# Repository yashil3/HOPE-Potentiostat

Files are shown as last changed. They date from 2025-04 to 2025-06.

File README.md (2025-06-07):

# Pocket Potentiostat
IEEE DeCal HOPE Final Project -- Potentiostat for applying cyclic voltammetry to electrolyte

- Blocks A, B, D, and E: uses OPA2277 high-precision operational amplifiers
- Block C: uses TL074 transimpedance amplifier
- Blocks F, G, and H: uses INA128 instrumentational amplifiers
- Block C uses a TL074 Transimpedance Amplifier (TIA). It is cost-effective, but it is not the best option (a really good one would be ~$40)
- May need to fix Rg resistor values based on how much the voltage in the electrodes varies

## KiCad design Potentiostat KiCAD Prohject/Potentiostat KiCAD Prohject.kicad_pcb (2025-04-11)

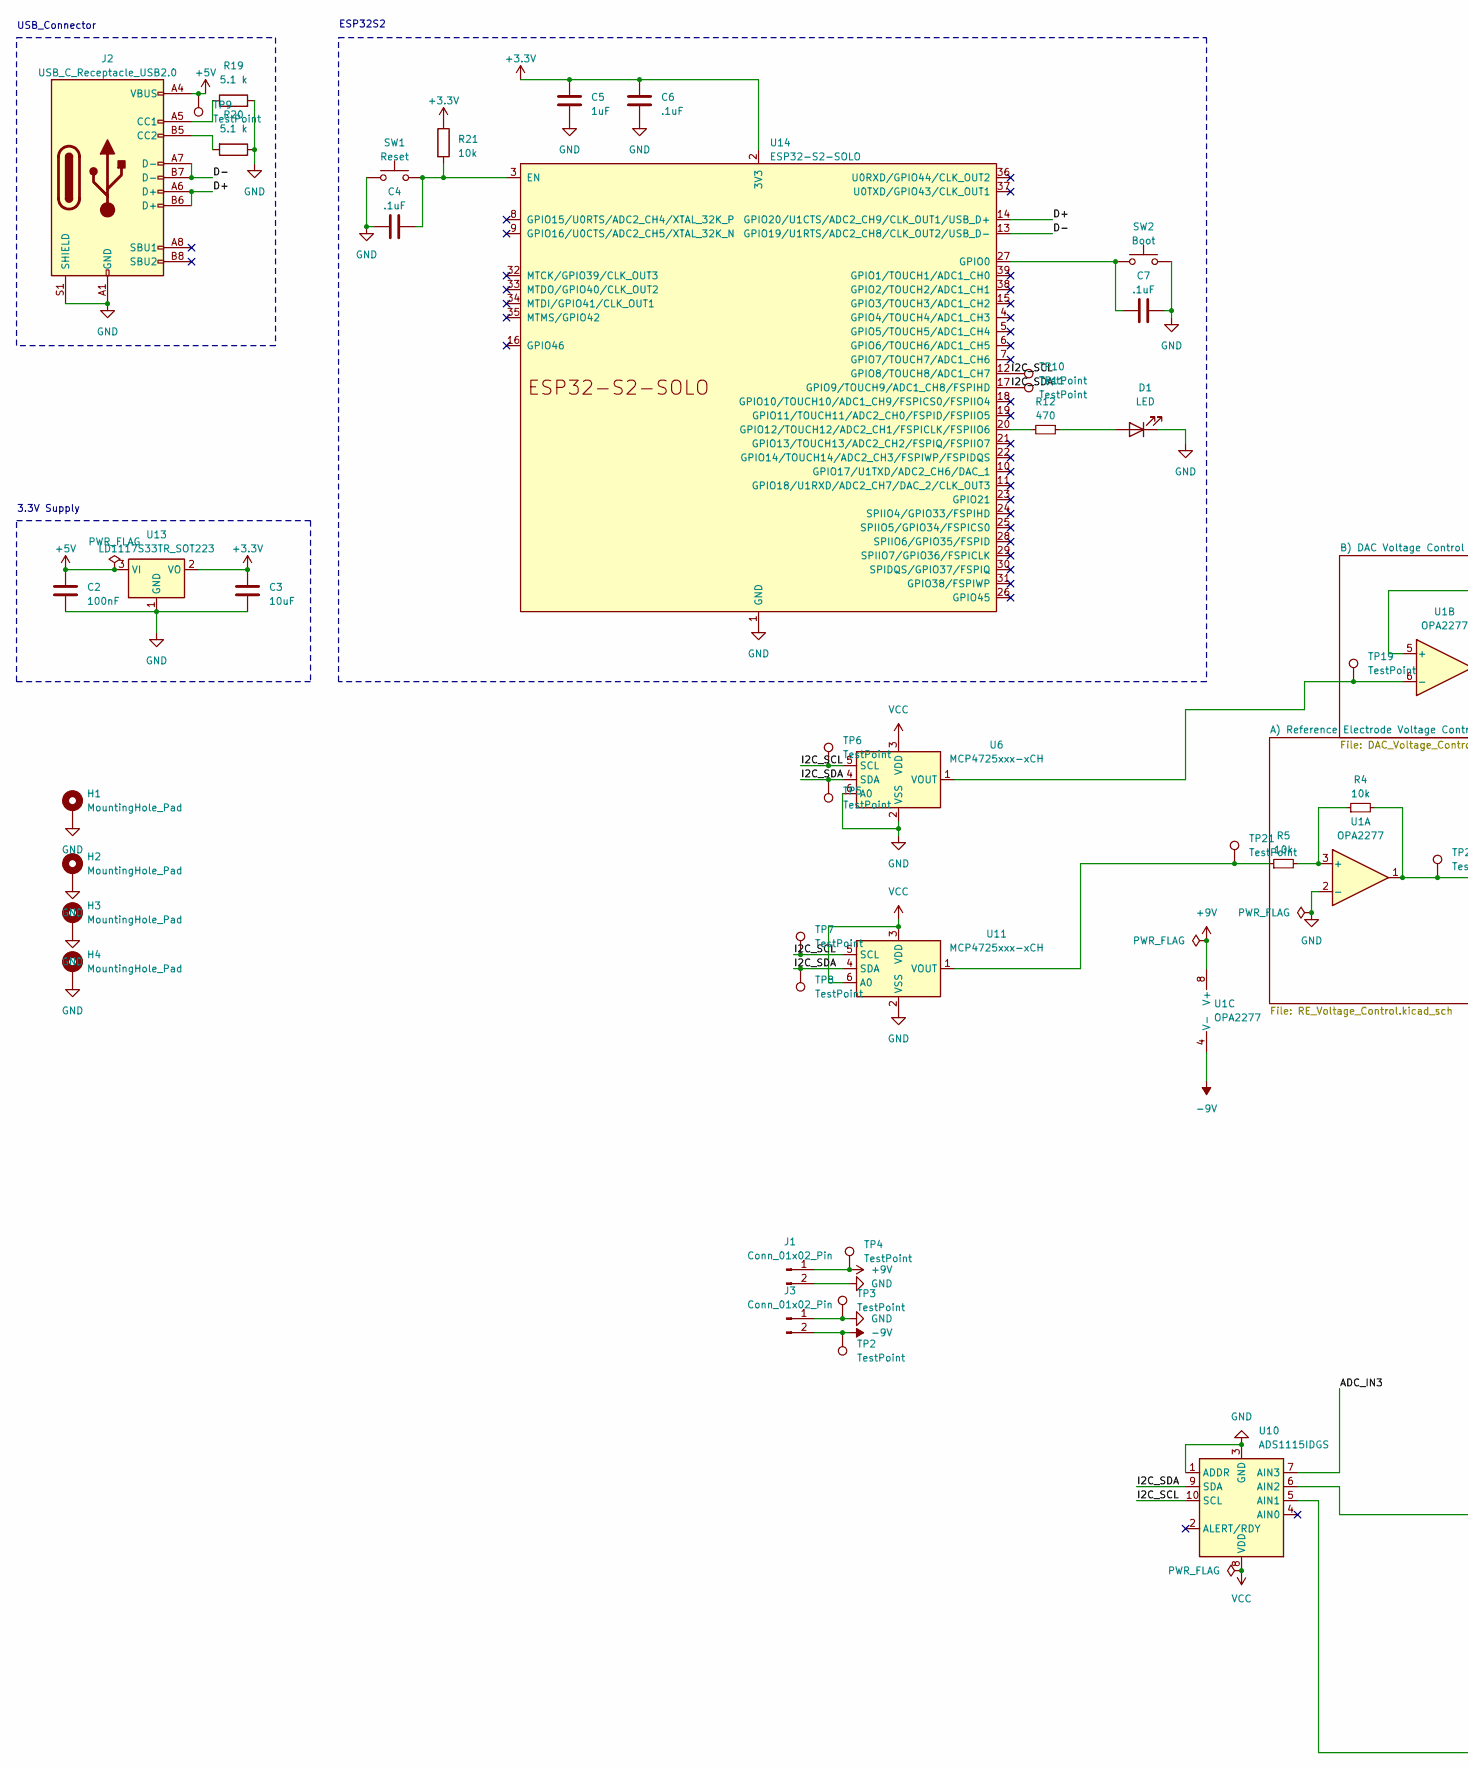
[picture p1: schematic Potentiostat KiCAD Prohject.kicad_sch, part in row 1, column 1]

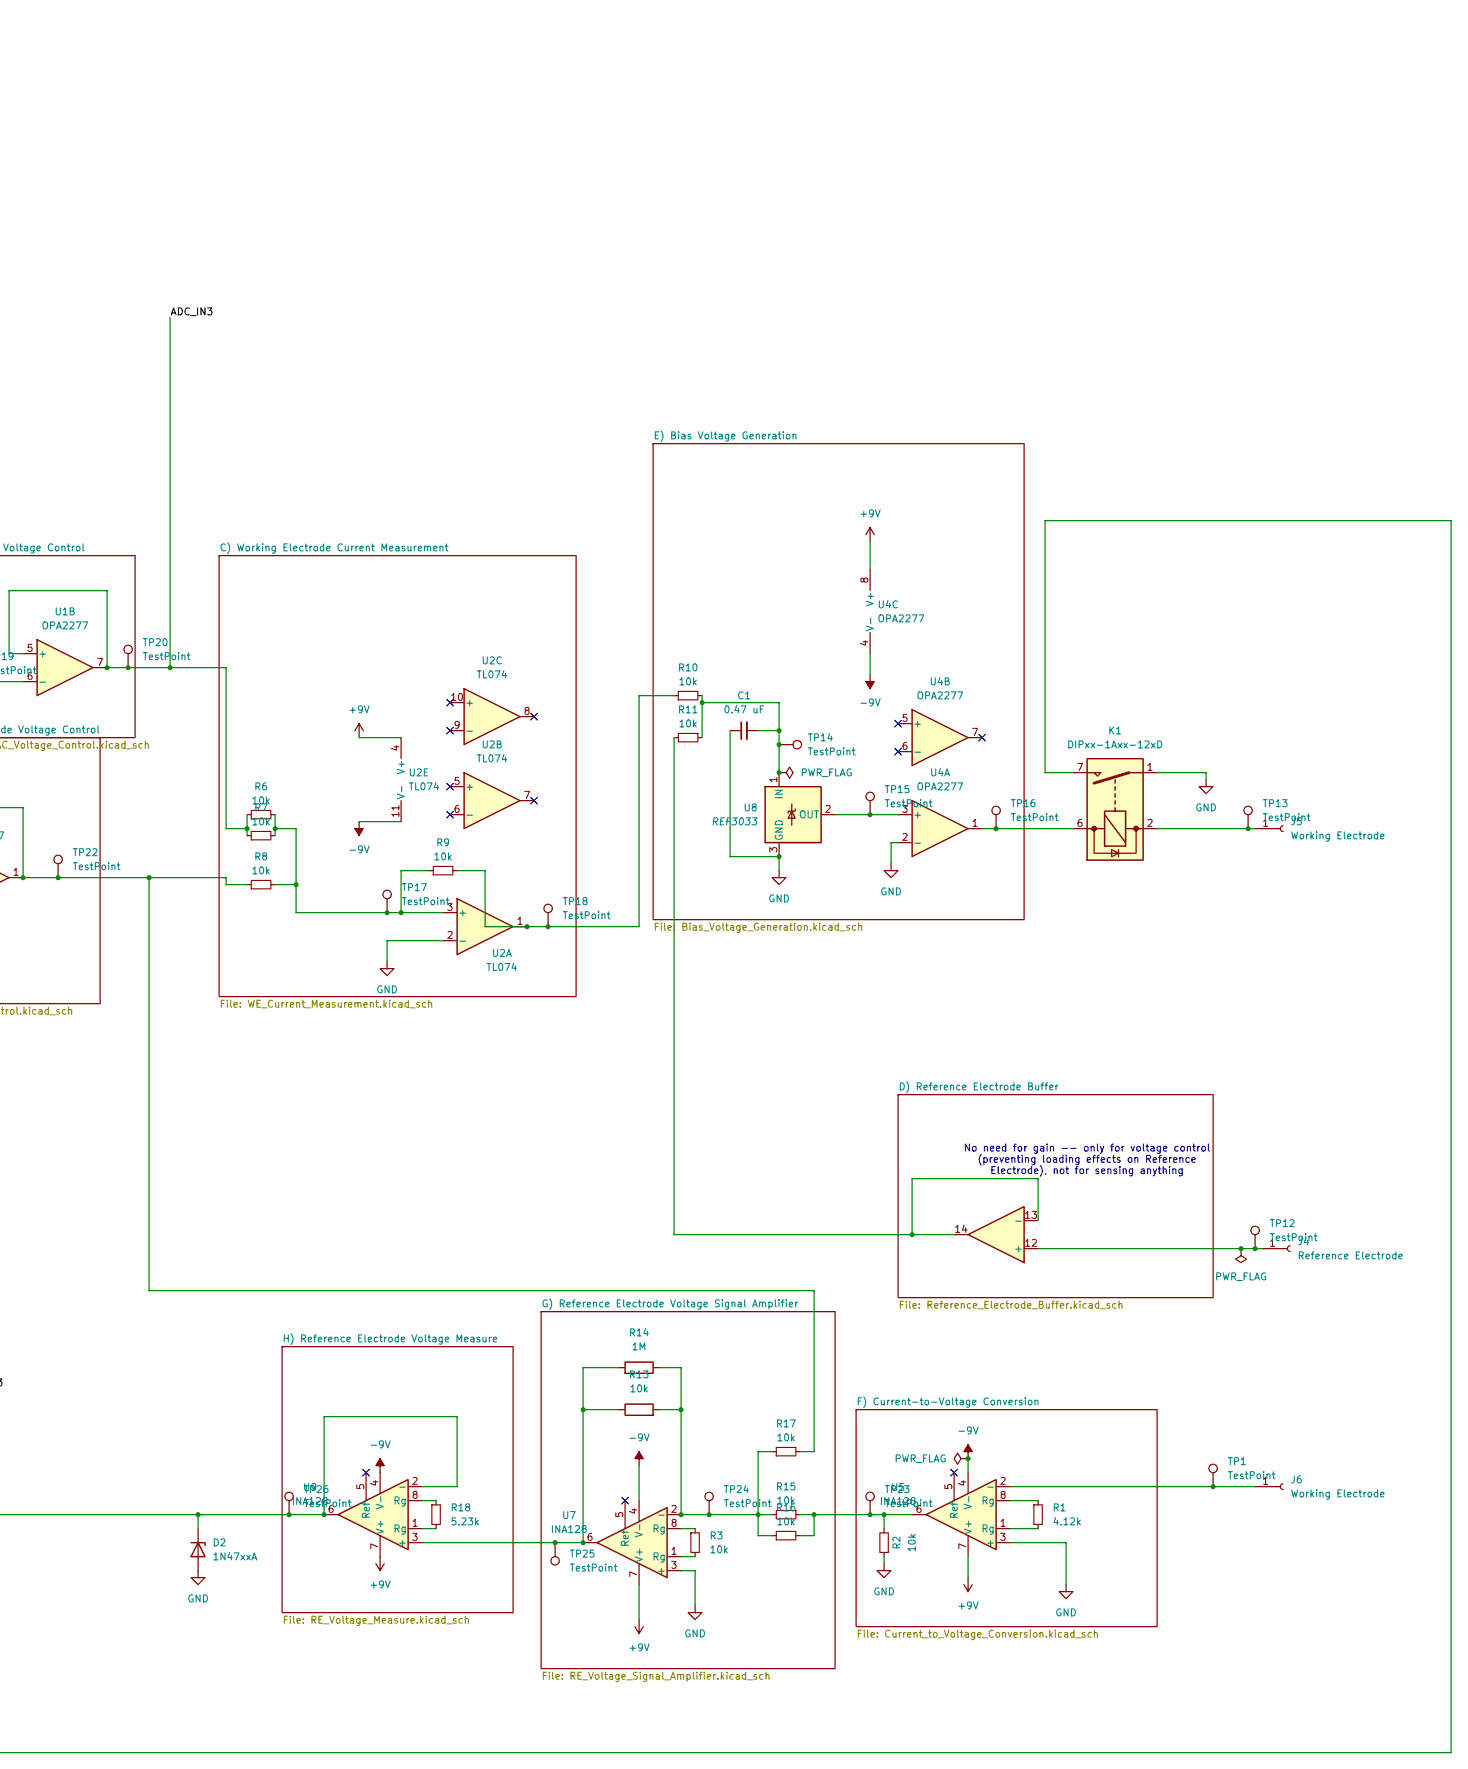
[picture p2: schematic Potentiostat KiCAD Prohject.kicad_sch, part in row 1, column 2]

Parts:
C1: 0.47 uF; CAPC7851084X4N
C2: 100nF; C_0603_1608Metric
C3: 10uF; C_0603_1608Metric
C4, C6, C7: .1uF; C_0603_1608Metric
C5: 1uF; C_0603_1608Metric
D1: LED; LED_0603_1608Metric
D2: 1N47xxA; D_DO-41_SOD81_P10.16mm_Horizontal
H1, H2, H3, H4: MountingHole_Pad
J1, J3: Conn_01x02_Pin; PinHeader_1x02_P2.54mm_Vertical
J2: USB_C_Receptacle_USB2.0; USB_C_Receptacle_GCT_USB4105-xx-A_16P_TopMnt_Horizontal
J4: Reference Electrode; CONN_575-8_KEY
J5, J6: Working Electrode; CONN_575-8_KEY
K1: DIPxx-1Axx-12xD; Relay_StandexMeder_DIP_LowProfile
R1: 4.12k; R_0603_1608Metric
R2, R3, R4, R5, R6, R7, R8, R9, R10, R11, R13, R15, R16, R17, R21: 10k; R_0603_1608Metric
R12: 470; R_0603_1608Metric
R14: 1M; R_0603_1608Metric
R18: 5.23k; R_0603_1608Metric
R19, R20: 5.1 k; R_0603_1608Metric
SW1: Reset; SW_Push_1P1T-SH_NO_CK_KMR2xxG
SW2: Boot; SW_Push_1P1T-SH_NO_CK_KMR2xxG
TP1, TP2, TP3, TP4, TP5, TP6, TP7, TP8, TP9, TP10, TP11, TP12, TP13, TP14, TP15, TP16, TP17, TP18, TP19, TP20, TP21, TP22, TP23, TP24, TP25, TP26: TestPoint; TestPoint_Pad_1.0x1.0mm
U1, U4: OPA2277; SOIC-8_3.9x4.9mm_P1.27mm
U2: TL074; SOIC-14_3.9x8.7mm_P1.27mm
U5, U7, U9: INA128; SOIC-8_3.9x4.9mm_P1.27mm
U6, U11: MCP4725xxx-xCH; SOT-23-6
U8: REF3033; SOT-23
U10: ADS1115IDGS; TSSOP-10_3x3mm_P0.5mm
U13: LD1117S33TR_SOT223; SOT-223-3_TabPin2
U14: ESP32-S2-SOLO

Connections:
+3.3V: C3.1, C5.1, C6.1, R21.1, U13.2 (VO), U14.2 (3V3)
+5V: C2.1, J2.A4 (VBUS), J2.A9 (VBUS), J2.B4 (VBUS), J2.B9 (VBUS), TP9.1, U13.3 (VI)
+9V: J1.1, TP4.1, U1.8 (V+), U2.4 (V+), U4.8 (V+), U5.7 (V+), U7.7 (V+), U9.7 (V+)
-9V: J3.2, TP2.1, U1.4 (V-), U2.11 (V-), U4.4 (V-), U5.4 (V-), U7.4 (V-), U9.4 (V-)
/ADC_IN3: R6.1, R7.1, TP20.1, U1.5 (+), U1.7, U10.7 (AIN3)
/D+: J2.A6 (D+), J2.B6 (D+), U14.14 (GPIO20/U1CTS/ADC2_CH9/CLK_OUT1/USB_D+)
/D-: J2.A7 (D-), J2.B7 (D-), U14.13 (GPIO19/U1RTS/ADC2_CH8/CLK_OUT2/USB_D-)
/I2C_SCL: TP6.1, TP7.1, TP10.1, U6.5 (SCL), U10.10 (SCL), U11.5 (SCL), U14.12 (GPIO8/TOUCH8/ADC1_CH7)
/I2C_SDA: TP5.1, TP8.1, TP11.1, U6.4 (SDA), U10.9 (SDA), U11.4 (SDA), U14.17 (GPIO9/TOUCH9/ADC1_CH8/FSPIHD)
GND: C1.1, C2.2, C3.2, C4.1, C5.2, C6.2, C7.2, D1.1 (K), D2.2 (A), H1.1, H2.1, H3.1, H4.1, J1.2, J2.A1 (GND), J2.A12 (GND), J2.B1 (GND), J2.B12 (GND), J2.S1 (SHIELD), J3.1, K1.1, K1.14, R2.1, R19.2, R20.1, SW1.1, SW2.2, TP3.1, U1.2 (-), U2.2 (-), U4.2 (-), U5.3 (+), U6.2 (VSS), U6.6 (A0), U7.3 (+), U8.3 (GND), U10.1 (ADDR), U10.3 (GND), U11.2 (VSS), U13.1 (GND), U14.1 (GND), U14.40 (GND), U14.41 (GND)
unnamed: D1.2 (A), R12.1
unnamed: D2.1 (K), TP26.1, U9.2 (-), U9.6, U10.6 (AIN2)
unnamed: J2.A5 (CC1), R19.1
unnamed: J2.B5 (CC2), R20.2
unnamed: J4.1, TP12.1, U2.12 (+)
unnamed: J5.1, K1.2, K1.13, TP13.1
unnamed: J6.1, TP1.1, U5.2 (-)
unnamed: K1.6, TP16.1, U4.1
unnamed: R1.1, U5.8 (Rg)
unnamed: R1.2, U5.1 (Rg)
unnamed: R3.1, U7.8 (Rg)
unnamed: R3.2, U7.1 (Rg)
unnamed: R9.2, R10.1, TP18.1, U2.1
unnamed: R2.2, R15.1, R16.2, TP23.1, U5.6
unnamed: R4.2, R8.1, R17.2, TP22.1, U1.1
unnamed: R18.1, U9.8 (Rg)
unnamed: R18.2, U9.1 (Rg)
unnamed: R4.1, R5.2, U1.3 (+)
unnamed: TP19.1, U1.6 (-), U6.1 (VOUT)
unnamed: R6.2, R7.2, R8.2, R9.1, TP17.1, U2.3 (+)
unnamed: R11.2, U2.13 (-), U2.14
unnamed: TP15.1, U4.3 (+), U8.2 (OUT)
unnamed: R13.2, R14.1, R15.2, R16.1, R17.1, TP24.1, U7.2 (-)
unnamed: C1.2, R10.2, R11.1, TP14.1, U8.1 (IN)
unnamed: R13.1, R14.2, TP25.1, U7.6, U9.3 (+)
unnamed: K1.7, K1.8, U10.5 (AIN1)
unnamed: R5.1, TP21.1, U11.1 (VOUT)
unnamed: C4.2, R21.2, SW1.2, U14.3 (EN)
unnamed: C7.1, SW2.1, U14.27 (GPIO0)
unnamed: R12.2, U14.20 (GPIO12/TOUCH12/ADC2_CH1/FSPICLK/FSPIIO6)
VCC: U6.3 (VDD), U10.8 (VDD), U11.3 (VDD), U11.6 (A0)

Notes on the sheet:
USB_Connector
No need for gain -- only for voltage control (preventing loading effects on Reference Electrode), not for sensing anything
3.3V Supply
ESP32S2

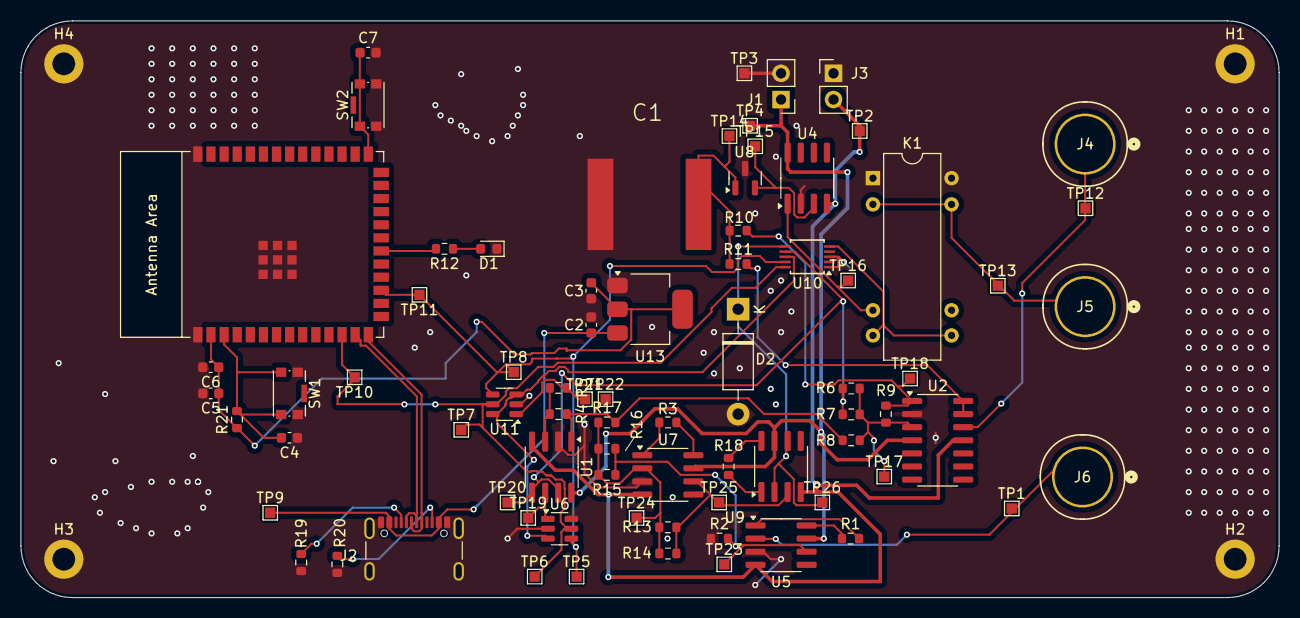
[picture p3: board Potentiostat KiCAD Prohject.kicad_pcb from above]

Board: 2 copper layers, 121.9 x 55.9 mm, 81 parts (0 on the bottom side), 41 nets.

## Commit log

2025-04-03 initial files
    [Bias_Voltage_Generation.kicad_sch, Current_to_Voltage_Conversion.kicad_sch, DAC_Voltage_Control.kicad_sch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]
2025-04-03 changed resistor values
    [Potentiostat KiCAD Prohject.kicad_sch]
2025-04-03 Add KiCad files to gitignore
2025-04-03 Add properly configured .gitignore for KiCad files
2025-04-04 completed ESP32 design
    [Bias_Voltage_Generation.kicad_sch, Current_to_Voltage_Conversion.kicad_sch, DAC_Voltage_Control.kicad_sch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]
2025-04-04 added missing footprints
2025-04-04 add microcontroller stuff
    [Potentiostat KiCAD Prohject.kicad_sch]
2025-04-09 esp32 solo and cleanup
    [Bias_Voltage_Generation.kicad_sch, Current_to_Voltage_Conversion.kicad_sch, DAC_Voltage_Control.kicad_sch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]
2025-04-09 updated wires
    [Potentiostat KiCAD Prohject.kicad_sch]
2025-04-10 Changed resistors and assigned footprints
    [Potentiostat KiCAD Prohject.kicad_pcb, Potentiostat KiCAD Prohject.kicad_sch]
2025-04-10 Redid layout with ground traces
    [Potentiostat KiCAD Prohject.kicad_pcb, Potentiostat KiCAD Prohject.kicad_sch]
2025-04-11 we're so back
    [Potentiostat KiCAD Prohject.kicad_pcb, Potentiostat KiCAD Prohject.kicad_sch]
2025-04-11 almost finished layout -- need test points
    [Potentiostat KiCAD Prohject.kicad_pcb, Potentiostat KiCAD Prohject.kicad_sch]
